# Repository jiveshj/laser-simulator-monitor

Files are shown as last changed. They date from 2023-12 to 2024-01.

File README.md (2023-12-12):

# laser-simulator-monitor

This board [(schematic)](Hardware/monitor_board/monitor_board.pdf)
is used for testing new or questionable laser controller boards.
See [github](https://github.com/BU-BOTLab/dDOSI_system/tree/main/Hardware/Electronics/laserDriverCircuit)
for details of the laser driver..  Here is an archived schematic (as of 12/12/23) for reference: 
[laserDriverCircuit.pdf](Documentation/laserDriverCircuit.pdf).

Here is a sketch of the wiring: [test_setup_wiring.png](Documentation/test_setup_wiring.png).

Here is a basic outline of the expected operation of the board when in use:

* Connect 12V external power to J4
* Connect power and monitoring cables (total of 4 cables) from this board to laser controller
* Connect a USB cable from the Arduino to a computer and set up a terminal program (putty or minicom)
* Connect a separate mini-DIN (round) cable between the laser driver
  and the controller (isolated I2C) board on the test setup
  
Power up the setup.  A test menu will appear and allow the user to interactively run a test.

See [(Software)](Software) for specs on the test code.

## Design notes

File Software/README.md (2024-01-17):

# Laser test setup software

## Preliminary Specification

### Overview

The test setup for a new laser board consists of 4 components:

* A laptop or PC running the main test program (Python/C++/Matlab)
* An Isolated I2C controller board connected by USB/serial to the PC
* A test monitor board also connected by USB (via Arduino pro micro)
  to the PC
* The DUT (device under test), a laser controller

Testing will be performed in several phases:

* Phase I - DUT with no laser or wavelength controller (aka WLD)
* Phase II - Install WLD and laser simulator
* Phase III - Install a real laser

The test is managed by an application program on a PC.  This program
can be written in any convenient language which can communicate with
devices over a USB emulated serial port (Windows `COM` port or linux
`/dev/ttyUSB` or `/dev/ttyACM`).

In addition, embedded programs written in `C/C++` run on AVR
microcontrollers on the I2C controller and test monitor boards.
These programs respond to simple single-line text commands and return
short responses.

### Communication with test boards

#### I2C controller

The I2C controller responds to many commands, but only a few are
useful here.  Send `h` (help) for a complete list.

    d             disable all connected lasers
	e 0           enable laser 0
	i 0 100       set laser 0 current to 100mA (up to 2500mA)
    n 0 250       set non-volatile (permanent) current to 250mA
	r 0           read data from laser 0
	
The `r` command returns output like this:

    IMON 0.000A
    PMON 0.025V
     VSET 0.012V
     TEMP  21.6
      VCC 2.502
    Laser V2.1 config

`VSET` should be close to what was set with the `i` command.

`VCC` is half the power supply voltage and should always be about 2.5V

`TEMP` is the temperature sensor on the laser board.

`IMON` and `PMON` are the monitor current and photodiode monitor
voltage as reported by the WLD controller.

#### Monitor board

The monitor board should respond to the following commands:

    r 0          read ADC channel 0
	r            read all ADC channels
	p 123        set digital pot to 123
	n 123        set digital pot nonvolatile to 123
	e            enable power to laser controller
	d            disable power to laser controller
	l 3          set LED control mask to 3 (both LEDs on)\
	i            read digital inputs

NOTE:  The monitor board V1.0 is designed using an Arduino Pro Micro
(Sparkfun design).  This board turns out to be difficult/impossible to
program without using the Arduino IDE.

The Pro Mini could be substituted as it is almost exactly the same
pinout, though and FTDI serial thing is required.
	
For now I suggest to use the Arduino environment on the Pro Micro.
All the hardware devices (ADC MCP3428, digi pot MCP4561) have libraries.

See https://github.com/jiveshj/laser-simulator-monitor directory
`Software/Arduino/SerialCommandExample` for a simple command parser.

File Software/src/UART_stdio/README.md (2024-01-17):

# UART_stdio

This example shows how the stdio.h facilities can be used in avr-libc.  Note that this is a pretty minimal subset of the standard library on a real OS.

See [the avr-libc manual](https://www.nongnu.org/avr-libc/user-manual/group__avr__stdio.html) for details.

In particular, there is no input editing (backspace, etc) are just put in the buffer.  See example code [uart.c](https://www.nongnu.org/avr-libc/examples/stdiodemo/uart.c) for how to fix this.

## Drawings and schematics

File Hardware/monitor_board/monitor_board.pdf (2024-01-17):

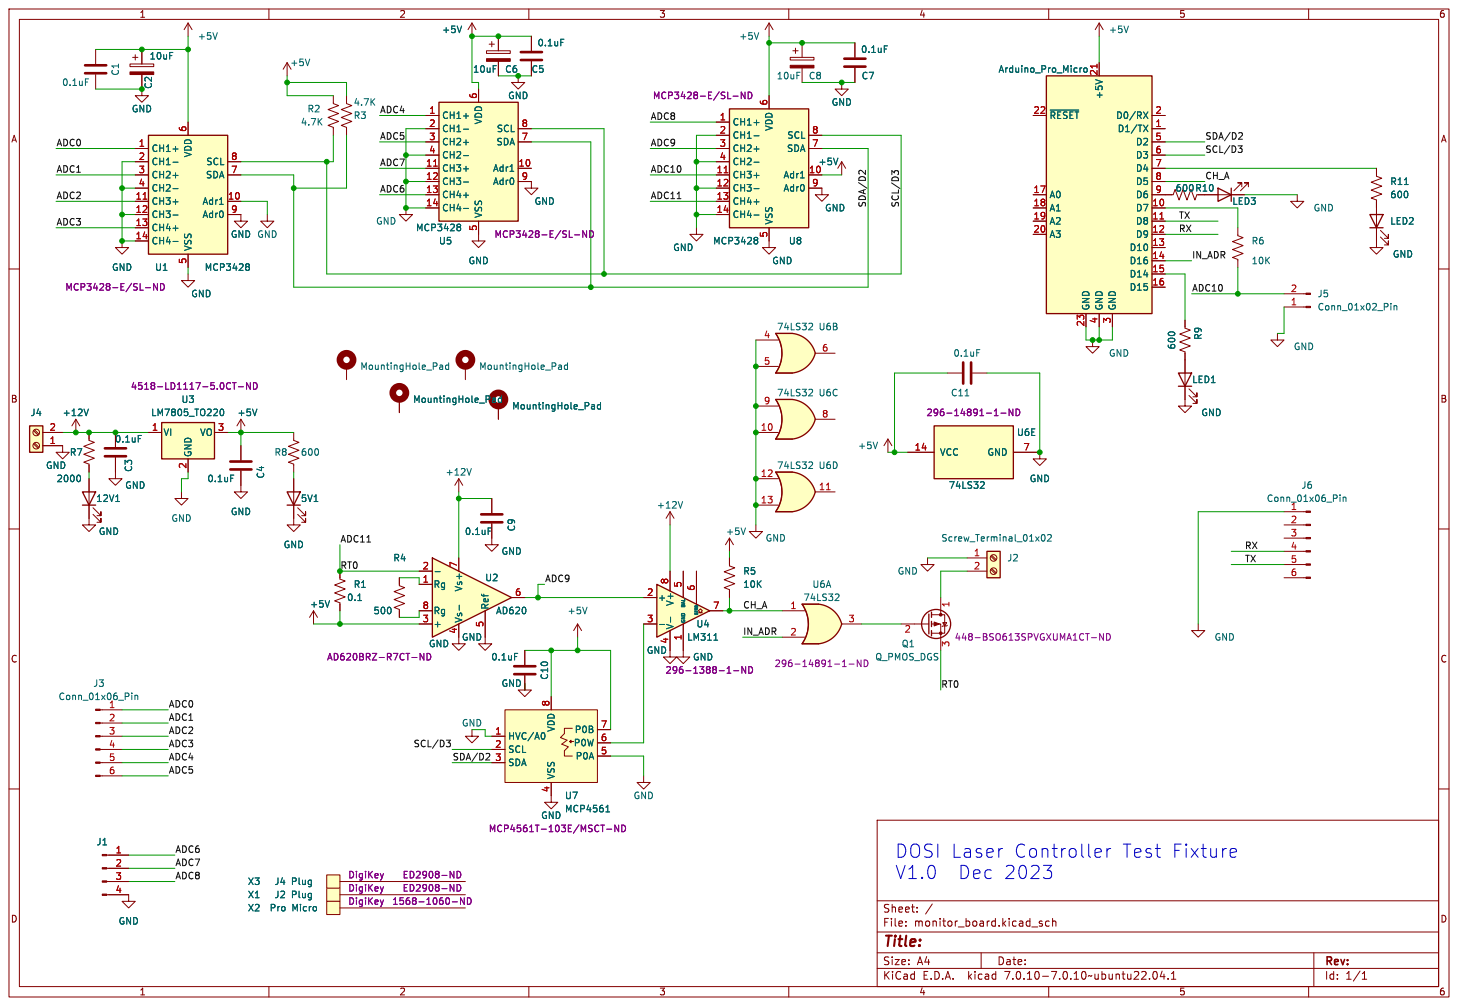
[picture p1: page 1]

6 SDA 7 SCL 8 Adr0 9 U5 MCP3428 MCP3428-E/SL-ND MountingHole_Pad GND

6 SDA 7 SCL 8 Adr0 9 GND GND

6 SDA 7 SCL 8 Adr0 9 MCP3428 U8 MCP3428-E/SL-ND GND

GND GND

6 SDA 7 SCL 8 Adr0 9 U1 MCP3428 MCP3428-E/SL-ND GND

8 U7 MCP4561 MCP4561T-103E/MSCT-ND GND GND

Id: 1/1 Title: File: monitor_board.kicad_sch Sheet: /

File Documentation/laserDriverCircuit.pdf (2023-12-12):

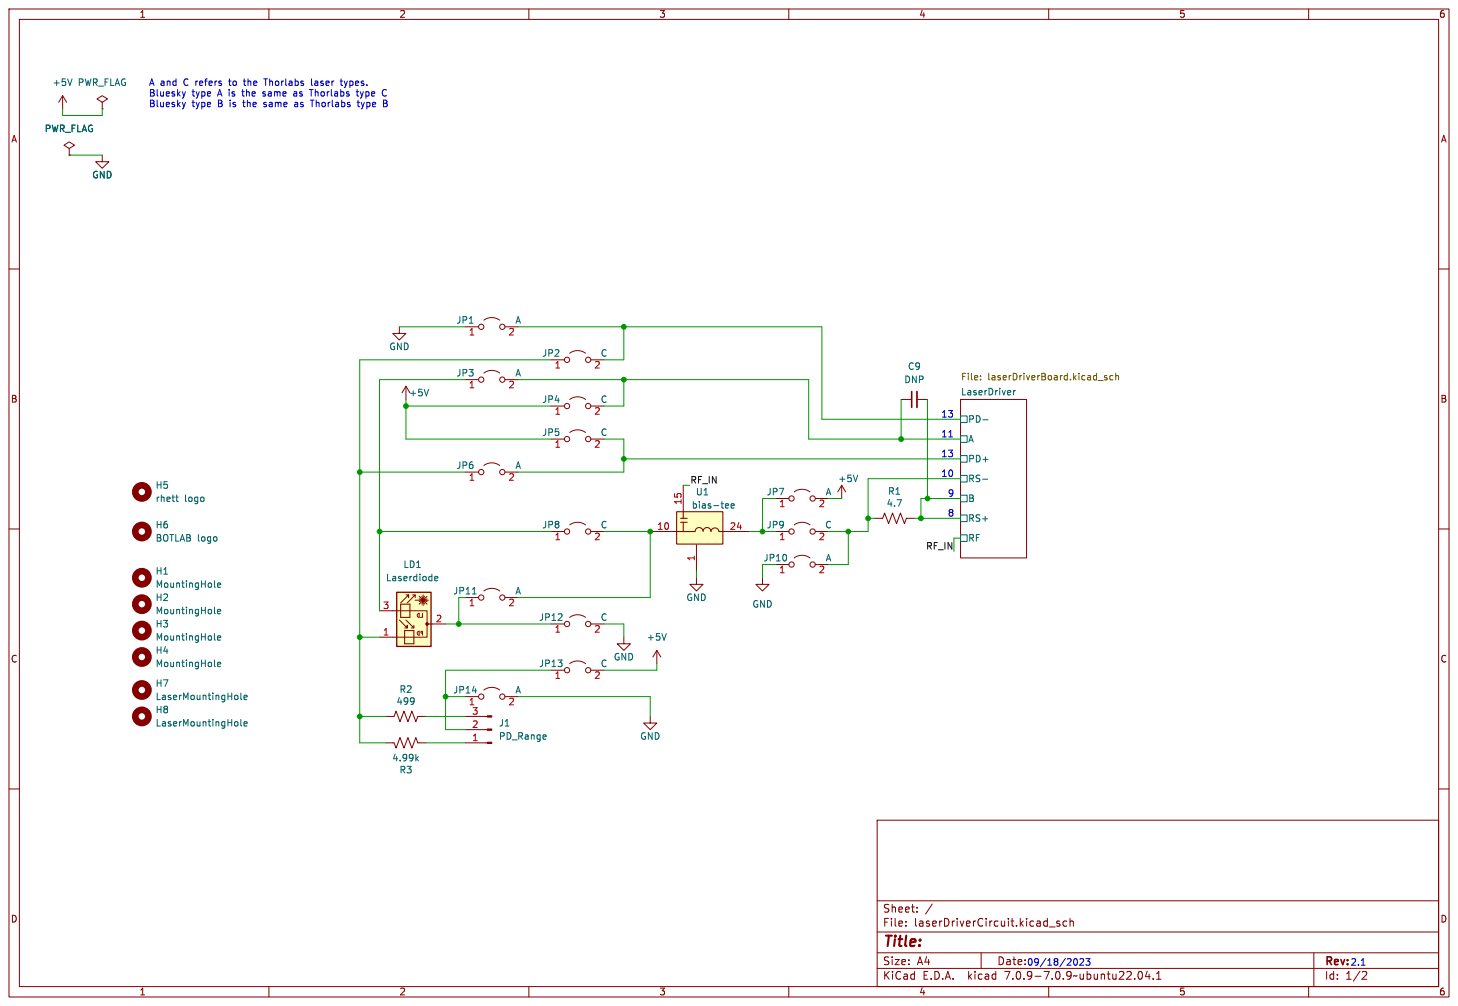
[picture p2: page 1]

13 A and C refers to the Thorlabs laser types. Bluesky type A is the same as Thorlabs type C

Bluesky type B is the same as Thorlabs type B

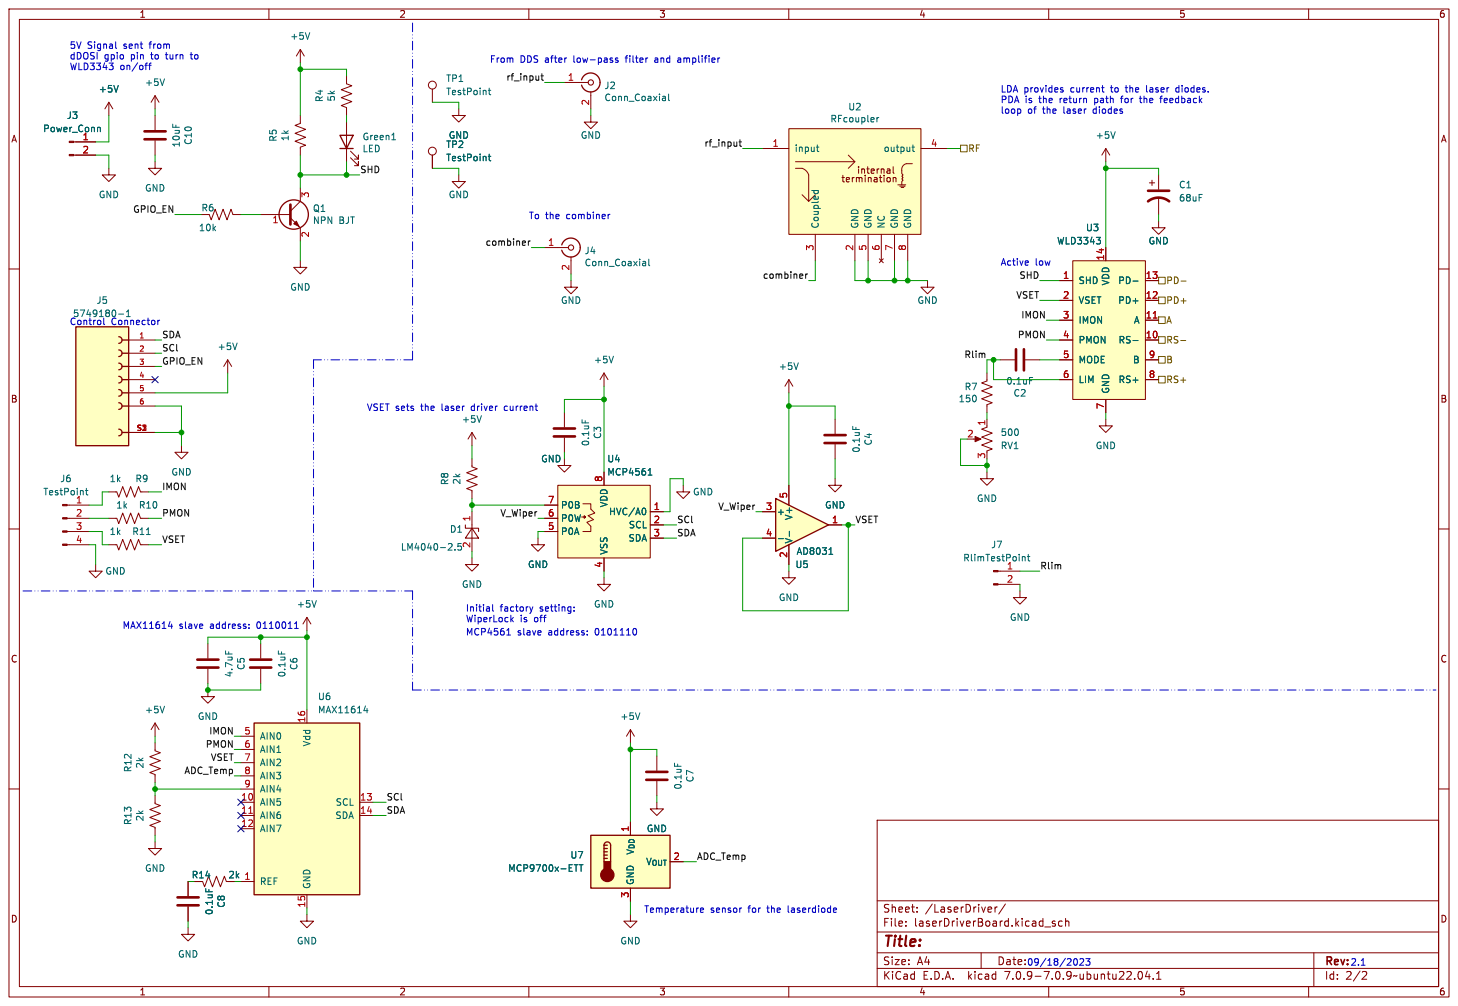
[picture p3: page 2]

2 3 Q1 NPN BJT GND R13 2k 10uF C10 +5V
Id: 2/2 Title: File: laserDriverBoard.kicad_sch Sheet: /LaserDriver/ C7 0.1uF R45k GND

LDA provides current to the laser diodes. PDA is the return path for the feedback

loop of the laser diodes

Active low MCP4561 slave address: 0101110

- 4 U4 MCP4561 HVC/A0 1 SCL 2 SDA 3 VSS

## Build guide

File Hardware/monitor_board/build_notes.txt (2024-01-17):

Suggested Assembly/Test Order:

0.  Check with meter, ensure open circuit between 12V and GND, 5V and GND

1.  Install all passives (R, C, LEDs)
    NOTE:  LED install with long lead in round pad hole

2.  Install U3

3.  Connect power supply to J4 (observe polarity, it is not marked!)
    Apply 12V power with 100mA current limit.

    check:  Note power supply current:  ____________________

	    5V1 LED lit
    	    12V1 LED lit
    	    +5V measures correct with meter
	    +12V measures correct with meter
	    Check 5V and 12V on power supply pins of all chips

4.  Install socket and Arduino
    Apply 12V power
    check:  Note power supply current:  ____________________
    	    Power LEDs still lit

5.  Install Aruino software
    Connect USB cable
    Set for board "Arduino Leonardo"
    Figure out port if needed

    Load "blinky" example and change to pin 14 where LED1 is connected

    Download and run, LED1 should blink.

    You should be very happy at this point!  The Arduino is working!

6.  Install U1

    Apply 12V power
    check:  Note power supply current:  ____________________
    	    Power LEDs still lit

    At this point we need some software

    Install the MCP342x library and get some of the examples working.

    Connect a 1k-10k potentiometer as follows:

    	    Top    - 5V
	    wiper  - ADC0 (J3 pin 1)
	    Bottom - GND

    Read the ADC channel 0 while you adjust the pot.
    Make a plot of ADC reading vs voltage, should be linear.

7.  Install U5, U8

    Apply 12V power
    check:  Note power supply current:  ____________________
    	    Power LEDs still lit

    Check with your pot connected to ADC4 and ADC8 that they work as well

8.  Install U7

    Apply 12V power
    check:  Note power supply current:  ____________________
    	    Power LEDs still lit

    Find and install the Arduino library for the digi pot (MCP4561)

    Test it:  changing the setting should change the voltage on pin 6 (or pin 3 of U4)

9.  Install U2

    Apply 12V power
    check:  Note power supply current:  ____________________
    	    Power LEDs still lit

    Test U2.  It is designed to measure current in the 0-1A range or so.
    Use ohm's law to choose a resistor to connect between RT0 and GND, read ADC9
    (or check the voltage at ADC9 with a meter) and confirm that it works as expected.

10. Install U4.

    Using your test resistor from step 9 and software to program the digi pot,
    measure the output of U4 (pin 7) and ensure that it works as expected.

11. Install U6.

    Test the logic.  When either pin 1 or pin 2 is high on U6, pin 3 should be high.

    (pin 1 is output of U4, pin 2 is Arduino D5)

12. Install Q1

    Connect a resistor (maybe with an LED) on J2

    Confirm that everything works correctly
    (current limit set with digi pot, enable with Arduino pin D5)

That's pretty much it for the hardware.

For the software, see ...Software/Arduino/SerialCommandExample
and the README in the Software directory to get started.

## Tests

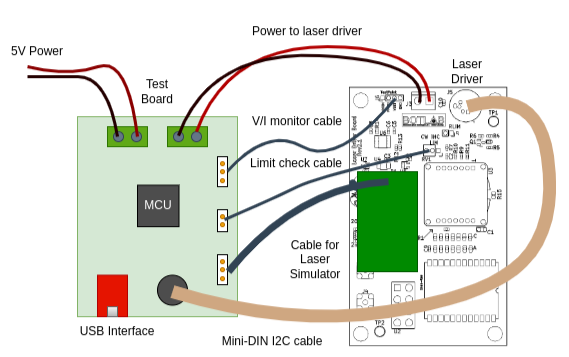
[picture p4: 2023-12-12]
Documentation/test_setup_wiring.png

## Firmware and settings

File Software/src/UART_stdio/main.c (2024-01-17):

/*
 * UART stdio example
 * note that there is no editing on input!
 */

#include <stdio.h>
#include <string.h>
#include <avr/io.h>
#include <util/delay.h>
#include "uart.h"

// Arduino LED is on PB5

#define LED_DDR DDRB
#define LED_BIT 5
#define LED_PORT PORTB

// create a file pointer for read/write to USART0
FILE usart0_str = FDEV_SETUP_STREAM(USART0SendByte, USART0ReceiveByte, _FDEV_SETUP_RW);

static char buff[40];

int main (void)
{
  unsigned char c = ' ';

  USART0Init();
  stdout = &usart0_str;		/* connect UART to stdout */
  stdin = &usart0_str;		/* connect UART to stdin */

  LED_DDR ^= (1 << LED_BIT);

  puts("UART test");

  while( 1) {
    puts("> ");
    fgets( buff, sizeof( buff), stdin);
    for( int i=0; i<strlen(buff); i++) {
      printf("%d: ", i);
      unsigned char c = buff[i];
      if( c < 0x20 || c > 0x7f)
	printf("0x%x\n", c);
      else
	printf("%c\n", c);
    }
  }
}

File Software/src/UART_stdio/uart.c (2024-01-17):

//
// very simple UART functions
//

#include <stdio.h>
#include "uart.h"

// initialize the UART.  Baud rate set in uart.h
void USART0Init(void)
{
  // Set baud rate
  UBRR0H = (uint8_t)(UBRR_VALUE>>8);
  UBRR0L = (uint8_t)UBRR_VALUE;
  // Set frame format to 8 data bits, no parity, 1 stop bit
  UCSR0C |= (1<<UCSZ01)|(1<<UCSZ00);
  //enable transmission and reception
  UCSR0B |= (1<<RXEN0)|(1<<TXEN0);
}

// send a byte.  stream is provided for stdio compatibility
// and may be NULL
int USART0SendByte(char u8Data, FILE *stream)
{
  if(u8Data == '\n')
    {
      USART0SendByte('\r', stream);
    }
  //wait while previous byte is completed
  while(!(UCSR0A&(1<<UDRE0))){};
  // Transmit data
  UDR0 = u8Data;
  return 0;
}


// return true if a character is available for input
int USART0CharacterAvailable()
{
  return (UCSR0A&(1<<RXC0));
}

// receive a byte, block in none available
// argument is ignored
// echo character
// convert <CR> to <LF>
int USART0ReceiveByte( FILE *stream)
{
  unsigned char c;
  // Wait for byte to be received
  while(!(UCSR0A&(1<<RXC0))){};
  // Return received data
  c = UDR0;
  USART0SendByte( c, NULL);
  if(c == '\r') {
    c = '\n';
    USART0SendByte( c, NULL);
  }
  return c;
}



void USART0GetString( char *buffer, int max)
{
  int n = 0;
  char *p = buffer;
  uint8_t c;

  while( 1) {
    c = USART0ReceiveByte( NULL);
    putchar( c);
    if( c == '\n') {
      *p++ = '\0';
      return;
    }
    if( c == '\b' && p > buffer) {
      putchar('\b');
      --p;
    } else {
      *p++ = c;
    }
    
  }
  
}

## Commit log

2023-10-04 Adding updated KICAD files
    [monitor_board.kicad_pcb, monitor_board.kicad_sch]
2023-10-18 Editing the schematic
    [monitor_board.kicad_sch]
2023-10-24 Edited the current schematic but isn't finished completely
    [monitor_board.kicad_sch]
2023-10-25 Newly revised schematic
    [monitor_board.kicad_sch]
2023-10-26 Neater Schematic
    [monitor_board.kicad_sch]
2023-11-01 Schematic with CatNo
    [monitor_board.kicad_sch]
2023-11-01 Footrprints also added in addition to CatNo
    [monitor_board.kicad_sch]
2023-11-01 Add extra BOM items and symbol
    [monitor_board.kicad_sch]
2023-11-07 Improved footprints and catNos
    [monitor_board.kicad_sch]
2023-11-07 a few schem footprints
    [monitor_board.kicad_sch]
2023-11-08 Editing the PCB layout
    [monitor_board.kicad_pcb, monitor_board.kicad_sch]
2023-11-14 Updated schematic and PCB
    [monitor_board.kicad_pcb, monitor_board.kicad_sch]
2023-11-14 routing demo
    [monitor_board.kicad_pcb]
2023-11-16 Updated PCB
    [monitor_board.kicad_pcb]
2023-11-16 Edited Schematic and PCB
    [monitor_board.kicad_pcb, monitor_board.kicad_sch]
2023-11-21 New PCB layout
    [monitor_board.kicad_pcb]
2023-11-28 New PCB and schematic
    [monitor_board.kicad_sch]
2023-11-29 schematic and PCB layout
    [monitor_board.kicad_sch]
2023-12-04 New schematic_footprint_12/4
    [monitor_board.kicad_pcb, monitor_board.kicad_sch]
2023-12-05 PCB Layout 12/5
    [monitor_board.kicad_pcb]
2023-12-07 Updated Schematic with Cat Nos
    [monitor_board.kicad_sch]
2023-12-07 Updated Schematic with new Cat Nos
    [monitor_board.kicad_sch]
2023-12-12 gerbers, readmes
    [monitor_board-B_Cu.gbr, monitor_board-B_Mask.gbr, monitor_board-B_Silkscreen.gbr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]
2023-12-12 Add serial connector
    [monitor_board-B_Cu.gbr, monitor_board-B_Mask.gbr, monitor_board-B_Silkscreen.gbr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]
2023-12-14 New PCB
    [monitor_board.kicad_pcb]
2023-12-14 New PCB+ Schematic
2023-12-14 Rev 1.0 as built
    [monitor_board-B_Cu.gbr, monitor_board-B_Mask.gbr, monitor_board-B_Silkscreen.gbr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]
2024-01-17 update readme, add Arduino, add build notes
